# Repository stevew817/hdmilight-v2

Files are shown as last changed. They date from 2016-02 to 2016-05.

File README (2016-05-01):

For latest version, go to http://hacks.esar.org.uk/

How to use:

1) Manufacture the HDMI receiver board that can be found in 
   the 'board' directory (CADSoft Eagle format).
2) Open the 'fpga/hdmilight.xise' project in Xilinx ISE and
   generate a bit file.
3) Edit the files under the config directory to configure
   the LEDs.
4) Edit 'Makefile' in the top level directory and set
   the DATA2MEM path for the Xilinx data2mem tool location
   on your system.
5) Run 'make' in the top level directory, which will build
   'tools/makemem', then the firmware image, then the config
   files, before merging the firmware and config into the
   final bitfile.
   The final result should be hdmilight.bit in the top
   level directory.
6) Upload hdmilight.bit to a Papilio Pro FPGA board
7) Install the HDMI receiver board on to the Papilio board.
8) Connect LED strips to output pins
9) Open a serial terminal to the Papilio
10) Connect HDMI source to receiver board
11) It should now be working.

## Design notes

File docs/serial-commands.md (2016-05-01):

Serial Console Commands
=======================

Get Area
--------

    GA index

* index (0-255): The index or range of indices of the area definition(s) that should be retrieved 

Set Area
--------

    SA index xmin xmax ymin ymax divshift

* index (0-255): The index or range of indices of the area definition(s) that should be set
* xmin (0-63): The left most column of the area's rectangle
* xmax (0-63): The right most column of the area's rectangle
* ymin (0-63): The upper row of the area's rectangle
* ymax (0-63): The lower row of the area's rectangle
* divshift (0-): The number of places to right-shift the accumulated R, G and B value for the area, or in other words the divisor used to calculate the average
 * 1 = divide by 2
 * 2 = divide by 4
 * 3 = divide by 8
 * etc.

Reset Area
----------

    RA

Get Colour Correction Matrix
----------------------------

    GC matrix row 

* matrix (0-15): The index or range of indices of the matrix(s) whose row(s) should be retrieved
* row (0-3): The index or range of indices of the row(s) that should be retrieved:
  * Row 0: defines how red input influences the output R, G and B
  * Row 1: defines how green input influences the output R, G and B
  * Row 2: defines how blue input influences the output R, G and B
  * Row 3: defines the constant value that should be applied to the output R, G and B

Set Colour Correction Matrix
----------------------------

    SC matrix row r g b

* matrix (0-15): The index or range of indices of the matrix(s) whose row(s) should be set
* row (0-3): The index or range of indices of the row(s) that should be set
* r (-255.999-255.999): The coefficient for R
* g (-255.999-255.999): The coefficient for G
* b (-255.999-255.999): The coefficient for B

Reset Colour Correction Matrix
------------------------------

    RC

The reset colour command resets all colour correction matrices to the identity matrix.

Get Delay
---------

    GD

Set Delay
---------

    SD frames usec smooth_ratio

* frames (0-7): The number of whole frames that the output should be delayed by
* usec (0-65535): The number of micro-seconds that the output should be delayed by
* smooth_ratio (0.000-1.000): A number that specifies how much of the new output colour comes from the previous output colour and how much comes from the current frame:
 * 0.000 = 100% from current frame
 * 1.000 = 100% from previous output

Reset Delay
-----------

    RD

The reset delay command disables all delay and temporal smoothing

Disable Format Switching
------------------------

    DF

The disable format switching command stops configurations from being loaded
from flash whenever the format of the incoming video changes.

Enable Format Switching
-----------------------

    EF

The enable format switching command enables loading of the configurations
specified in the format table when the input video format changes.

Get Gamma
---------

    GG table channel index

* table (0-7): The index or range of indices of the gamma correction table(s) whose values should be retrieved
* channel (0-2): The index or range of indices of the colour channel(s) whose values should be retrieved: 
 * 0 = red
 * 1 = green
 * 2 = blue
* index: The index or range of indices of the row(s) that should be retrieved (0-255)

Set Gamma
---------

    SG table channel index value

* table (0-7): The index or range of indices of the gamma correction table(s) whose values should be set
* channel (0-2): The index or range of indices of the colour channel(s) whose values should be set
* index (0-255): The index or range of indices of the row(s) that should be set

Reset Gamma
-----------

    RG

The reset gamma command resets all gamma tables to a linear ramp (gamma 1.0)

Get I2C
-------

    GI addr subaddr

* addr (0-255): The address of the component within the ADV7611 that should be queried:
 * IO: 0x98
 * CP: 0x44
 * HDMI: 0x68
 * Repeater: 0x64
 * EDID: 0x6C
 * InfoFrame: 0x7C
 * CEC: 0x80
 * DPLL: 0x4C
* subaddr (0-255): The address within the component that should be queried

Set I2C
-------

    SI addr subaddr value

* addr (0-255): The address of the component within the ADV7611 that should be queried:
 * IO: 0x98
 * CP: 0x44
 * HDMI: 0x68
 * Repeater: 0x64
 * EDID: 0x6C
 * InfoFrame: 0x7C
 * CEC: 0x80
 * DPLL: 0x4C
* subaddr (0-255): The address within the component that should be queried
* value (0-255): The value that should be written to the register

Reset I2C
---------

    RI

The reset I2C command sets the registers as described in the table
in config_hdmi.h

Get Memory
----------

    GM index

* index (0-63): The index of the configuration that should be retrieved from flash

Get Output Map
--------------

    GO output light

* output (0-7): The index or indices of the output channels whose mapping should be retrieved
* light (0-511): The index or indices of the LED(s) whose mapping should be retrieved

Set Output Map
--------------

    SO output light area colour gamma enable

* output (0-7): The index or indices of the output channels whose mapping should be set
* light (0-511): The index or indices of the LED(s) whose mapping should be set
* area (0-255): The index of the area definition that the LED(s) should use
* colour (0-15): The index of the colour matrix that the LED(s) shoudl use
* gamma (0-7): The index of the gamma table that the LED(s) should use
* enable (0-1): 
 * 1 = enabled
 * 0 = disabled

Reset Output
------------

    RO

The reset output command sets the first 256 LEDs for all outputs to use the 256 area definitions in order, so LED 0 uses area 0, LED 1 uses area 1, and so on. All LEDs are set to use colour matrix 0 and gamma table 0. The remaining 256 LEDs on each output are disabled.

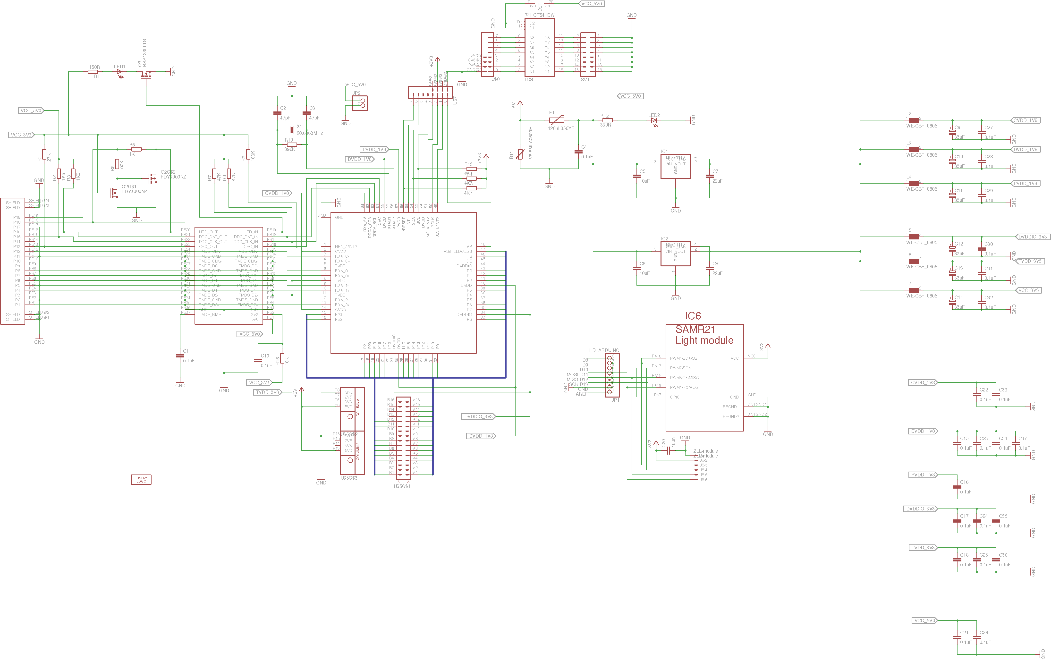
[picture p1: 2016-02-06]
board/hdmilight-schematic-v1.1-Duo.png

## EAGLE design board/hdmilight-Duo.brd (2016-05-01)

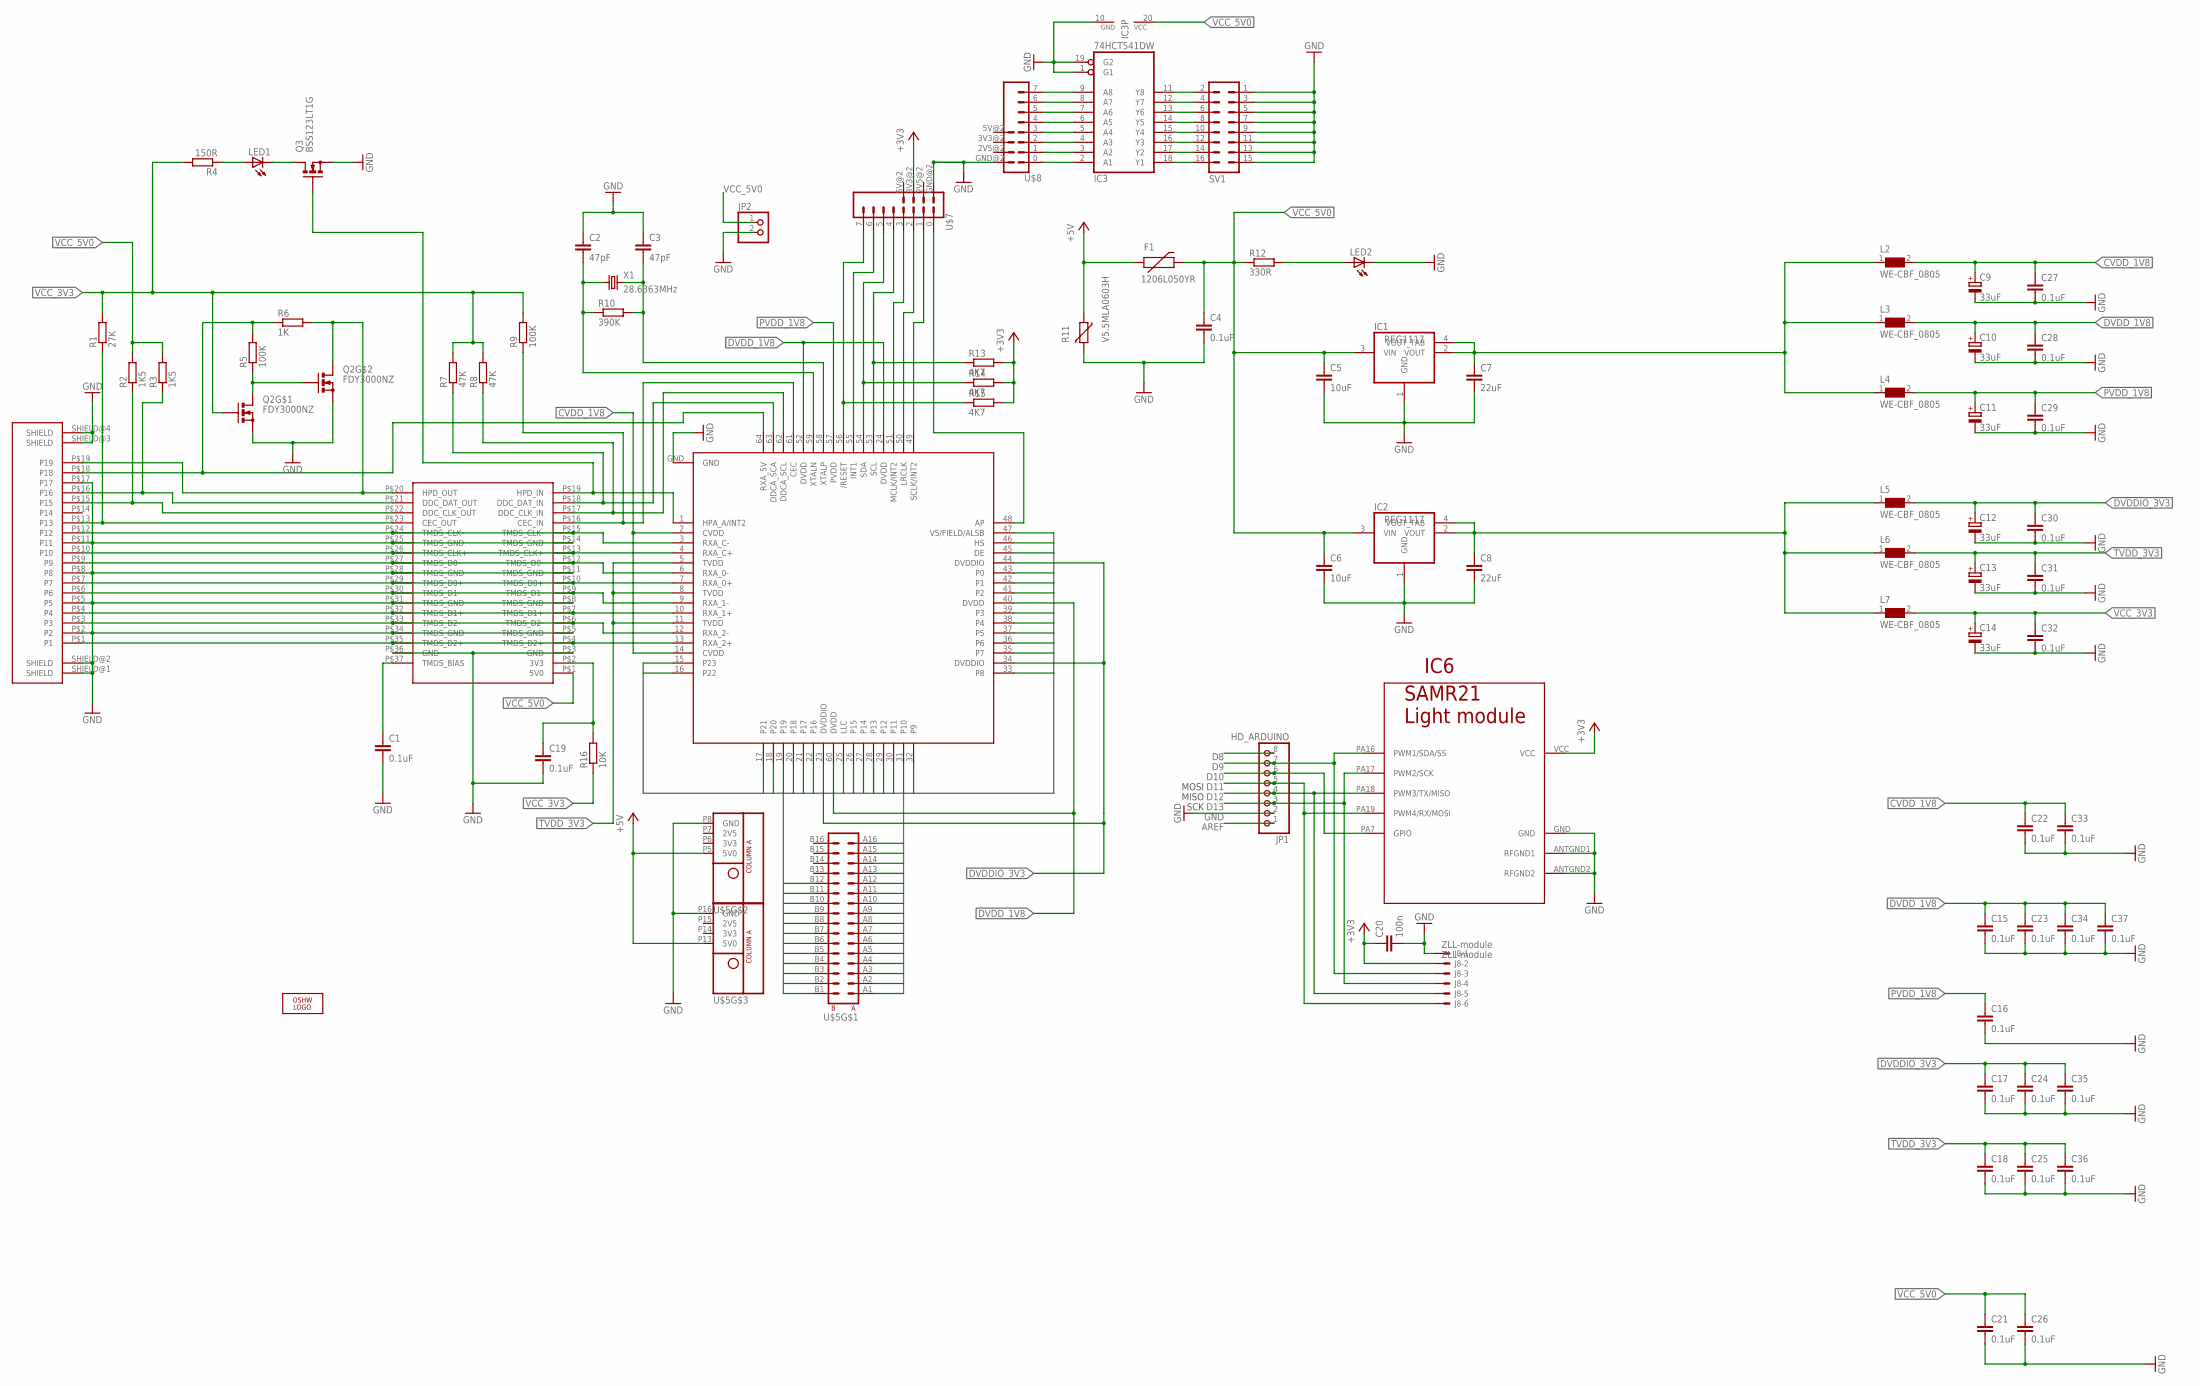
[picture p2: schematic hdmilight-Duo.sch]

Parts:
C1, C4, C16, C17, C19, C21, C22, C24, C26, C27, C28, C29, C30, C31, C32, C33: 0.1uF; C0603
C2, C3: 47pF; C0603
C5, C6: 10uF; C1210
C7, C8: 22uF; C1206
C9, C10, C11, C12, C13, C14: 33uF; SMC_B
C15, C18, C23, C25, C34, C35, C36, C37: 0.1uF; C0402
C20: 100n; C0603K
F1: 1206L050YR; PTC-1206
IC1, IC2: REG1117; SOT223
IC3: 74HCT541DW; SO20W
IC4: ADV7611; TQFP64-10X10
IC5: TPD12S520; TSSOP38
IC6: SAMR21-MODLL; SAMR21-LLMOD
J1: FCI_HDMI_SOCKET_10029449-001RCF
J8: ZLL-module; 331-06
JP1: HD_ARDUINO; 1X08/OCT
JP2: PINHD-1X2/OCT; 1X02/OCT
L2, L3, L4, L5, L6, L7: WE-CBF_0805; 0805
LED1, LED2: LEDCHIP-LED0805; CHIP-LED0805
LOGO1: OSHW_LOGO_FILLX0200-NT; OSHW_FILLX200_NOTEXT
Q2: FDY3000NZ; SC89-6
Q3: BSS123LT1G; SOT23
R1: 27K; R0603
R2, R3: 1K5; R0603
R4: 150R; R0603
R5, R9: 100K; R0603
R6: 1K; R0603
R7, R8: 47K; R0603
R10: 390K; R0603
R11: V5.5MLA0603H; CT/CN0603
R12: 330R; R0603
R13, R14, R15: 4K7; R0603
R16: 10K; R0603
SV1: MA08-2
U$5: WING32_HALF; WING32_HALF_NOHOLES
U$7, U$8: WING8WING8_NOHOLES; WINGSIDE_8BIT_NOHOLES
X1: 28.6363MHz; SM49

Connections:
+3V3: C20.1, IC6.VCC, J8.3, R13.2, R14.2, R15.2, U$7.3V3@2 (3V3)
+5V: F1.1, R11.1, U$5.P5 (5V0), U$5.P13 (5V0)
AP: IC4.48 (AP), U$7.0 (1)
AREF: JP1.1
CVDD_1V8: C9.+, C22.1, C27.1, C33.1, IC4.2 (CVDD), IC4.14 (CVDD), L2.2
D8: JP1.8
D9: IC6.PA16 (PWM1/SDA/SS), J8.5, JP1.7
D10: IC6.PA7 (GPIO), JP1.6
D11: IC6.PA19 (PWM4/RX/MOSI), J8.11, JP1.5
D12: IC6.PA18 (PWM3/TX/MISO), J8.9, JP1.4
D13: IC6.PA17 (PWM2/SCK), J8.7, JP1.3
DE: IC4.45 (DE), U$5.B2
DVDDIO_3V3: C12.+, C17.1, C24.1, C30.1, C35.1, IC4.23 (DVDDIO), IC4.34 (DVDDIO), IC4.44 (DVDDIO), L5.2
DVDD_1V8: C10.+, C15.1, C23.1, C28.1, C34.1, C37.1, IC4.24 (DVDD), IC4.40 (DVDD), IC4.52 (DVDD), IC4.60 (DVDD), L3.2
GND: C1.2, C2.1, C3.1, C4.2, C5.2, C6.2, C7.2, C8.2, C9.-, C10.-, C11.-, C12.-, C13.-, C14.-, C15.2, C16.2, C17.2, C18.2, C19.2, C20.2, C21.2, C22.2, C23.2, C24.2, C25.2, C26.2, C27.2, C28.2, C29.2, C30.2, C31.2, C32.2, C33.2, C34.2, C35.2, C36.2, C37.2, IC1.1 (GND), IC2.1 (GND), IC3.1 (G1), IC3.10 (GND), IC3.19 (G2), IC4.GND, IC5.P$3 (GND), IC5.P$5 (TMDS_GND), IC5.P$8 (TMDS_GND), IC5.P$11 (TMDS_GND), IC5.P$14 (TMDS_GND), IC5.P$25 (TMDS_GND), IC5.P$28 (TMDS_GND), IC5.P$31 (TMDS_GND), IC5.P$34 (TMDS_GND), IC5.P$36 (GND), IC6.ANTGND1 (RFGND1), IC6.ANTGND2 (RFGND2), IC6.GND, J1.P$2 (P2), J1.P$5 (P5), J1.P$8 (P8), J1.P$11 (P11), J1.P$17 (P17), J1.SHIELD@1 (SHIELD), J1.SHIELD@2 (SHIELD), J1.SHIELD@3 (SHIELD), J1.SHIELD@4 (SHIELD), J8.1, JP1.2, JP2.2, LED2.C, Q2.P$1 (S), Q2.P$4 (S), Q3.2 (S), R11.2, SV1.1, SV1.3, SV1.5, SV1.7, SV1.9, SV1.11, SV1.13, SV1.15, U$5.P8 (GND), U$5.P16 (GND), U$7.GND@2 (GND), U$8.GND@2 (GND)
HS: IC4.46 (HS), U$5.A1
INT1: IC4.55 (INT1), U$7.6 (7)
LLC: IC4.25 (LLC), U$5.A14
LRCLK: IC4.50 (LRCLK), U$7.2 (3)
MCLK: IC4.51 (MCLK/INT2), U$7.3 (4)
unnamed: IC4.13 (RXA_2+), IC5.P$4 (TMDS_D2+), IC5.P$35 (TMDS_D2+), J1.P$1 (P1)
unnamed: IC4.12 (RXA_2-), IC5.P$6 (TMDS_D2-), IC5.P$33 (TMDS_D2-), J1.P$3 (P3)
unnamed: IC4.10 (RXA_1+), IC5.P$7 (TMDS_D1+), IC5.P$32 (TMDS_D1+), J1.P$4 (P4)
unnamed: IC4.9 (RXA_1-), IC5.P$9 (TMDS_D1-), IC5.P$30 (TMDS_D1-), J1.P$6 (P6)
unnamed: IC4.7 (RXA_0+), IC5.P$10 (TMDS_D0+), IC5.P$29 (TMDS_D0+), J1.P$7 (P7)
unnamed: IC4.6 (RXA_0-), IC5.P$12 (TMDS_D0-), IC5.P$27 (TMDS_D0-), J1.P$9 (P9)
unnamed: IC4.4 (RXA_C+), IC5.P$13 (TMDS_CLK+), IC5.P$26 (TMDS_CLK+), J1.P$10 (P10)
unnamed: IC4.3 (RXA_C-), IC5.P$15 (TMDS_CLK-), IC5.P$24 (TMDS_CLK-), J1.P$12 (P12)
unnamed: IC3.9 (A8), U$8.7 (8)
unnamed: IC3.8 (A7), U$8.6 (7)
unnamed: IC3.7 (A6), U$8.5 (6)
unnamed: IC3.6 (A5), U$8.4 (5)
unnamed: IC5.P$23 (CEC_OUT), J1.P$13 (P13), R1.1
unnamed: IC5.P$22 (DDC_CLK_OUT), J1.P$15 (P15), R2.1
unnamed: IC5.P$21 (DDC_DAT_OUT), J1.P$16 (P16), R3.1
unnamed: IC5.P$20 (HPD_OUT), J1.P$19 (P19), Q2.P$3 (D), R6.2
unnamed: IC3.5 (A4), U$8.3 (4)
unnamed: IC3.4 (A3), U$8.2 (3)
unnamed: LED2.A, R12.2
unnamed: IC4.62 (DDCA_SCL), IC5.P$17 (DDC_CLK_IN), R8.1
unnamed: C8.1, IC2.2 (VOUT), IC2.4 (VOUT_TAB), L5.1, L6.1, L7.1
unnamed: C7.1, IC1.2 (VOUT), IC1.4 (VOUT_TAB), L2.1, L3.1, L4.1
unnamed: IC4.63 (DDCA_SCA), IC5.P$18 (DDC_DAT_IN), R7.1
unnamed: IC4.61 (CEC), IC5.P$16 (CEC_IN), R9.1
unnamed: C2.2, IC4.59 (XTALN), R10.1, X1.1
unnamed: C3.2, IC4.58 (XTALP), R10.2, X1.2
unnamed: C1.1, IC5.P$37 (TMDS_BIAS)
unnamed: IC3.3 (A2), U$8.1 (2)
unnamed: IC3.2 (A1), U$8.0 (1)
unnamed: IC3.11 (Y8), SV1.2
unnamed: IC3.12 (Y7), SV1.4
unnamed: IC3.13 (Y6), SV1.6
unnamed: IC3.15 (Y4), SV1.10
unnamed: IC3.16 (Y3), SV1.12
unnamed: IC3.17 (Y2), SV1.14
unnamed: IC3.18 (Y1), SV1.16
unnamed: IC3.14 (Y5), SV1.8
unnamed: C19.1, IC5.P$2 (3V3), R16.2
unnamed: Q2.P$5 (G), Q2.P$6 (D), R5.1
unnamed: IC4.64 (RXA_5V), J1.P$18 (P18), R5.2, R6.1
unnamed: LED1.A, R4.1
unnamed: LED1.C, Q3.3 (D)
unnamed: IC4.1 (HPA_A/INT2), IC5.P$19 (HPD_IN), Q3.1 (G)
NRESET: IC4.56 (/RESET), R15.1, U$7.7 (8)
P0: IC4.43 (P0), U$5.A2
P1: IC4.42 (P1), U$5.B3
P2: IC4.41 (P2), U$5.A3
P3: IC4.39 (P3), U$5.B4
P4: IC4.38 (P4), U$5.A4
P5: IC4.37 (P5), U$5.B5
P6: IC4.36 (P6), U$5.A5
P7: IC4.35 (P7), U$5.B6
P8: IC4.33 (P8), U$5.A6
P9: IC4.32 (P9), U$5.B7
P10: IC4.31 (P10), U$5.A7
P11: IC4.30 (P11), U$5.B8
P12: IC4.29 (P12), U$5.A8
P13: IC4.28 (P13), U$5.B9
P14: IC4.27 (P14), U$5.A9
P15: IC4.26 (P15), U$5.B10
P16: IC4.22 (P16), U$5.A10
P17: IC4.21 (P17), U$5.B11
P18: IC4.20 (P18), U$5.A11
P19: IC4.19, U$5.B12
P20: IC4.18 (P20), U$5.A12
P21: IC4.17 (P21), U$5.A13
P22: IC4.16 (P22), U$5.A15
P23: IC4.15 (P23), U$5.A16
PVDD_1V8: C11.+, C16.1, C29.1, IC4.57 (PVDD), L4.2
SCL: IC4.53 (SCL), R13.1, U$7.4 (5)
SCLK: IC4.49 (SCLK/INT2), U$7.1 (2)
SDA: IC4.54 (SDA), R14.1, U$7.5 (6)
TVDD_3V3: C13.+, C18.1, C25.1, C31.1, C36.1, IC4.5 (TVDD), IC4.8 (TVDD), IC4.11 (TVDD), L6.2
VCC_3V3: C14.+, C32.1, L7.2, Q2.P$2 (G), R1.2, R4.2, R7.2, R8.2, R9.2, R16.1
VCC_5V0: C4.1, C5.1, C6.1, C21.1, C26.1, F1.2, IC1.3 (VIN), IC2.3 (VIN), IC3.20 (VCC), IC5.P$1 (5V0), JP2.1, R2.2, R3.2, R12.1
VS: IC4.47 (VS/FIELD/ALSB), U$5.B1

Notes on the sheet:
MOSI
MISO
SCK

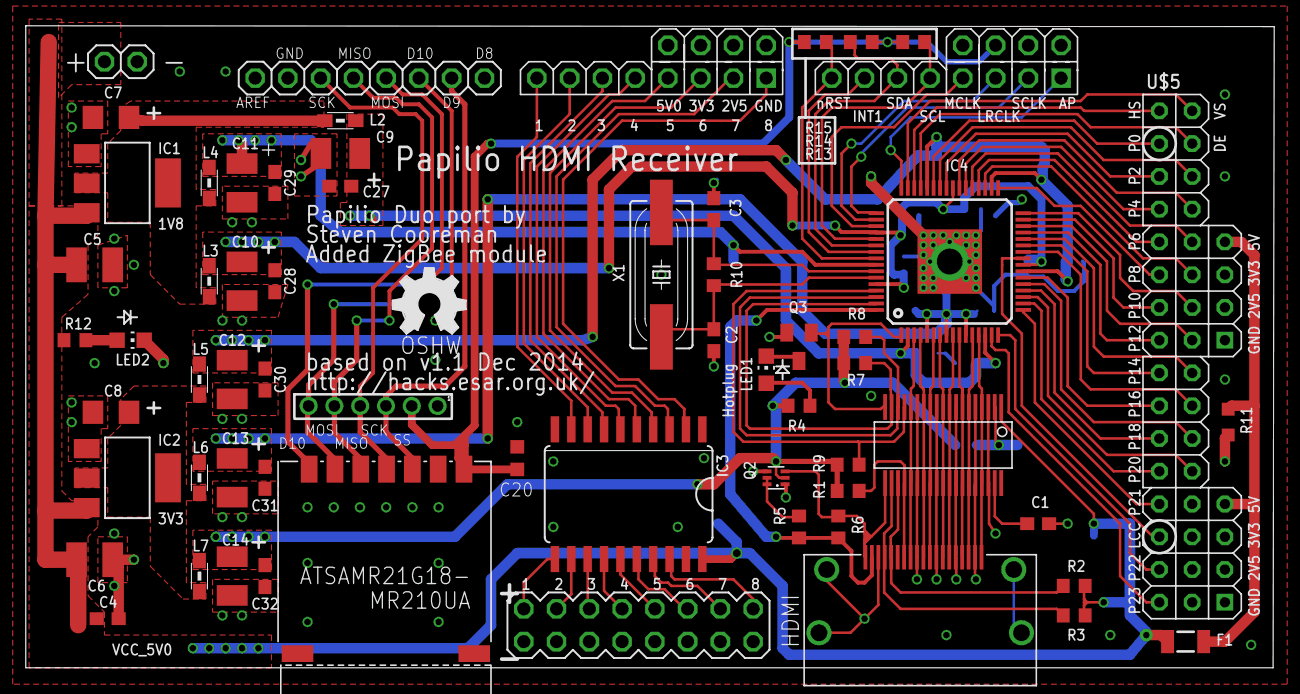
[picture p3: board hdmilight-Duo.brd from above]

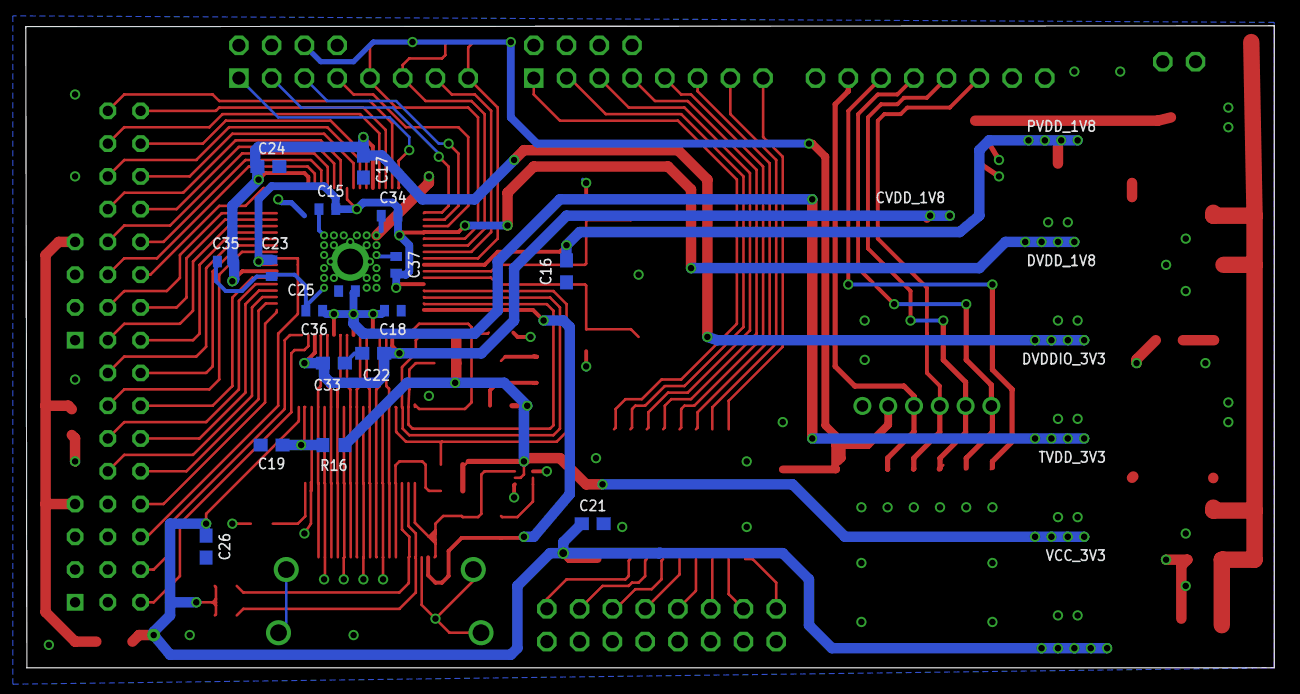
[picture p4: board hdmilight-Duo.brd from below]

Board: 2 copper layers, 96.8 x 49.8 mm, 80 parts (17 on the bottom side), 94 nets.

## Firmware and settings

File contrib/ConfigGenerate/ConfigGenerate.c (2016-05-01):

/*

   Copyright (C) 2015 Jetty

   This file is part of HDMI-Light

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
*/

#include <stdio.h>
#include <math.h>

/*
	Generates a basic Hdmilight configuration that has strips of LEDs wired in the following order on 1 output.  The intention
	is to provide a simple configuration to begin with, that can be adapted later:

	Wire in this order:
		Power/Data -> Top (Going Left to Right)
		Right (Going Top to Bottom)
		Bottom (Going Right to Left)
		Left (Going Bottom to Top)

	The following files are generated:
		area.conf
		output_N.conf

	It's assumed that top/bottom led strips  have the same number of leds and left/right leds strips have the same number of leds

	The total number of LEDS must be <=512
*/

// The number of the output we want to generate the files for
#define	OUTPUT_NUM 0 	// Valid values are 0-7 (and integer) and map to outputs 1-8 on the Hdmilight v2 board

// Set to the width / height of the picture (you can obtain this via the GF (get format) command in the serial interface
#define PIXELS_WIDTH  1916	// Must be integer
#define PIXELS_HEIGHT 1080	// Must be integer

// LEDS_X * 2 + LEDS_Y * 2  must be <= 512, if it's not, then your configuration will span more than 1 output, and this
// tool is not for you
#define LEDS_X	64	// Number of X leds (number of LEDs in each of the Top and Bottom Rows), must be integer
#define LEDS_Y	36	// Number of Y leds (number of LEDs in each of the Left and Right Columns, must be integer

// Fine tuning the bounds of the screen
// The screen is divided into a grid of cells of VIDEO_SCALING x VIDEO_SCALING in pixels by the FPGA
// Because the picture may not fit completely in the cell grid, we provide the opportunity here to adjust the 
// the bounds of the cell grid.  Negative values will shift the cell grid boudns to the left, and positive values to the right.
// The starting offsets should be >= 0, and values -2 to 2 would be normal.
// Start off with the values at 0, if you have a left most led in X that is not displaying a color, the video is out of bounds,
// increase by 1 and try again.  If the right most led in X is not correct, then you will want to decrease the end X offset by 1
//
// The cell grid could like this before adjustment, where P is the picture.  Both P and X are units of VIDEO_SCALING * VIDEO_SCALING
// in size:
//  X X X X X X X X X X X X X
//  X P P P P P P P P P P P X
//  X P P P P P P P P P P P X
//  X P P P P P P P P P P P X
//  X P P P P P P P P P P P X
//  X P P P P P P P P P P P X
//
//  To fix this and achieve:
//  P P P P P P P P P P P
//  P P P P P P P P P P P
//  P P P P P P P P P P P
//  P P P P P P P P P P P
//  P P P P P P P P P P P
//
//	CELLGRID_BOUNDS_START_X_OFFSET 	1
//	CELLGRID_BOUNDS_END_X_OFFSET	-1
//	CELLGRID_BOUNDS_START_Y_OFFSET 	1
//	CELLGRID_BOUNDS_END_Y_OFFSET	0
//
#define CELLGRID_BOUNDS_START_X_OFFSET 	0	// Adjustment to the first cell we want to use for the LEDS, must be >=0, typically <=2 and integer
#define CELLGRID_BOUNDS_END_X_OFFSET	0	// Adjustment to the last cell we want to use for the LEDS, typically -2 to +2 and integer
#define CELLGRID_BOUNDS_START_Y_OFFSET 	0	// Adjustment to the first cell we want to use for the LEDS, must be >=0, typically <=2 and integer
#define CELLGRID_BOUNDS_END_Y_OFFSET	0	// Adjustment to the last cell we want to use for the LEDS, typically -2 to +2 and integer

// The cell grid is further divided into areas which surround the outside the screen
// The following are in units of cells and are integers.  The minimum size is 1 cell.
// 
// For the top/bottom rows, AREA_WIDTH is in X and AREA_DEPTH is in Y, i.e AREA_WIDTH=2, AREA_DEPTH = 8, defines an area that is sized
// X: 2 * VIDEO_SCALING and Y:8 * VIDEO_SCALING
//
// For the left/right columns, AREA_WIDTH is in Y and AREA_DEPTH is in X, i.e AREA_WIDTH=2, AREA_DEPTH = 8, defines an area that is sized
// Y: 2 * VIDEO_SCALING and X:8 * VIDEO_SCALING
//
// Normally, where you have more LEDs than cells, you would have an AREA_WIDTH = 1
// If you have significantly fewer LEDS than cells, then AREA_WIWDTH = 2, or maybe 3
//
// AREA_DEPTH controls have far the sample area stretches from the edges of the screen.  Larger numbers take a large
// sample area to calculate the resulting color of the LED
//
// AREA_WIDTH * AREA_HEIGHT must be a power of 2 i.e. valid values are 1, 2, 4, 8, 16, 32 etc.
//
// The number of areas must be <= 255, therefore:
//	 ( ((ceilf(PIXELS_WIDTH / VIDEO_SCALING) / AREA_WIDTH) * 2 + 
//	   ((ceilf(PIXELS_HEIGHT / VIDEO_SCALING) / AREA_WIDTH) * 2 ) must be less than 255
#define AREA_WIDTH 1	// >=1 and integer:  Typically 1 or 2 (if you have fewer LEDs per strip)
#define AREA_DEPTH 8	// >=1 and integer:  Start at 8, and reduce after you've tuned CELLGRID_BOUNDS

// Defining the letter box ratio avoids having to change the CELLGRID_BOUNDS and LEDS_BOUNDS
// for different Letterbox formats at the same resolution.
// To use this, define CELLGRID_BOUNDS / LEDS_BOUNDS for the base resolution defined in PIXELS_WIDTH/HEIGHT,
// and then generate configs with a different LETTERBOX_RATIO for the letterboxes required
// Note that the base letterbox ratio is calculated from PIXELS_WIDTH/HEIGHT, so if that ratio is 1.77,
// and LETTERBOX_RATIO is 1.77, then there is no change made to the bounds of the screen
// Letterbox ratio must be > 0.0
#define LETTERBOX_RATIO 1.77	// 16:9
//#define LETTERBOX_RATIO 2.40	// Modern anamorphic (2-4-0)
//#define LETTERBOX_RATIO 1.33	// 4:3

// If the span of leds exceed the displayed picture area, there will be leds that should be dark,
// but because they are not are causing leds to not line up with the picture.
// Force the leds to be ignored by adjusting the bounds of the LED causing outermost leds to be ignored 
#define LEDS_BOUNDS_START_X_OFFSET 	0	// Adjustment to the first led we want to use, must be >=0, typically <=2 and integer
#define LEDS_BOUNDS_END_X_OFFSET	0	// Adjustment to the last led we want to use, must be <= 0, typically >=-2 and integer
#define LEDS_BOUNDS_START_Y_OFFSET 	0	// Adjustment to the first led we want to use, must be >=0, typically <=2 and integer
#define LEDS_BOUNDS_END_Y_OFFSET	0	// Adjustment to the last led we want to use, must be <=0, typically <=-2 and integer

// The color value for the output table for leds in use
#define COLOR_ACTIVE 0

// The color value for the output table for leds that are disabled
// Set this color in the color_N.conf to black (0's for everything)
#define COLOR_DISABLED 1

// The gamma value for the output table
#define GAMMA 1




// DO NOT CHANGE BELOW HERE
#define VIDEO_SCALING 32	// Incoming video is scaled down by this amount in X/Y by the FPGA.  I.e. 1920x1080 / 32 = 60x33
				// Scaling is independent of resolution, so 640x480 is 20x15

#define AREA_CONF		"area.conf"
#define OUTPUT_CONF_PART1	"output_"
#define OUTPUT_CONF_PART2	".conf"

#define LEDS_WIDTH  ((LEDS_X) + (LEDS_BOUNDS_END_X_OFFSET) - (LEDS_BOUNDS_START_X_OFFSET))
#define LEDS_HEIGHT ((LEDS_Y) + (LEDS_BOUNDS_END_Y_OFFSET) - (LEDS_BOUNDS_START_Y_OFFSET))

#define LETTERBOX_FUDGE_FACTOR (0.01)

#define SCREEN_ASPECT_RATIO ((float)(PIXELS_WIDTH) / (float)(PIXELS_HEIGHT))



// Returns true if v is integer
// otherwise false

int isInteger(float v)
{
	if (((float)((int)v)) == v )	return 1;
	else				return 0;
}



// Verifies the settings are valid
// Returns true if okay, otherwise false

int verifySettings(void)
{
	if ( OUTPUT_NUM < 0 || OUTPUT_NUM > 7 || ( ! isInteger(OUTPUT_NUM) ) )	{fprintf(stderr, "Error: OUTPUT_NUM should be 0..7 and integer\n");return 0;}
	if ( PIXELS_WIDTH < 1 || (! isInteger(PIXELS_WIDTH) ) )			{fprintf(stderr, "Error: PIXELS_WIDTH should be >=1 and integer\n");return 0;}
	if ( PIXELS_HEIGHT < 1 || (! isInteger(PIXELS_HEIGHT) ) )		{fprintf(stderr, "Error: PIXELS_HEIGHT should be >=1 and integer\n");return 0;}
	if ( LEDS_X < 1 || (! isInteger(LEDS_X) ) )				{fprintf(stderr, "Error: LEDS_X should be >=1 and integer\n");return 0;}
	if ( LEDS_Y < 1 || (! isInteger(LEDS_Y) ) )				{fprintf(stderr, "Error: LEDS_Y should be >=1 and integer\n");return 0;}

	if (( LEDS_X * 2 + LEDS_Y * 2 ) > 512)
		{fprintf(stderr, "Error: Total number of LEDs is greater than 512 and will exceed 1 output, this utility is not for you!\n");return 0;}

	if ( CELLGRID_BOUNDS_START_X_OFFSET < 0 || (! isInteger(CELLGRID_BOUNDS_START_X_OFFSET) ) )
										{fprintf(stderr, "Error: CELLGRID_BOUNDS_START_X_OFFSET should be >=0 and integer\n");return 0;}
	if ( ! isInteger(CELLGRID_BOUNDS_END_X_OFFSET) )			{fprintf(stderr, "Error: CELLGRID_BOUNDS_END_X_OFFSET should be integer\n");return 0;}
	if ( CELLGRID_BOUNDS_START_Y_OFFSET < 0 || (! isInteger(CELLGRID_BOUNDS_START_Y_OFFSET) ) )
										{fprintf(stderr, "Error: CELLGRID_BOUNDS_START_Y_OFFSET should be >=0 and integer\n");return 0;}
	if ( ! isInteger(CELLGRID_BOUNDS_END_Y_OFFSET) )			{fprintf(stderr, "Error: CELLGRID_BOUNDS_END_Y_OFFSET should be integer\n");return 0;}
	if ( AREA_WIDTH < 1 || (! isInteger(AREA_WIDTH) ) )			{fprintf(stderr, "Error: AREA_WIDTH should be >=1 and integer\n");return 0;}
	if ( AREA_DEPTH < 1 || (! isInteger(AREA_DEPTH) ) )			{fprintf(stderr, "Error: AREA_DEPTH should be >=1 and integer\n");return 0;}
	
	// Test for a power of 2 by shifting to the right
	int size = AREA_WIDTH * AREA_DEPTH;
	while ( size > 0 )
	{
		// Tes for more than one bit set
		if ( size > 1 && (size & 1))	break;
		size >>= 1;	// Shift right
	}

	// If size is not zero, then we broke out of the while above due to more than one bit being set
	// If size is 0, then we only had one bit set (i.e. a power of 2)
	if ( size )	{fprintf(stderr, "Error: AREA_WIDTH * AREA_DEPTH should be a power of 2\n");return 0;}

	if  ( ((ceilf((float)PIXELS_WIDTH  / (float)VIDEO_SCALING) / (float)AREA_WIDTH) * 2.0 +
	      ((ceilf((float)PIXELS_HEIGHT / (float)VIDEO_SCALING) / (float)AREA_WIDTH) * 2.0) ) > 255.0 )
			{fprintf(stderr, "Error: 255 Areas exceeded, increase AREA_WIDTH by 1\n");return 0;}

	if ( LEDS_BOUNDS_START_X_OFFSET < 0 || ( ! isInteger(LEDS_BOUNDS_START_X_OFFSET) ) )
		{fprintf(stderr, "Error: LEDS_BOUNDS_START_X_OFFSET should be >=0 and integer\n");return 0;}
	if ( LEDS_BOUNDS_START_Y_OFFSET < 0 || ( ! isInteger(LEDS_BOUNDS_START_Y_OFFSET) ) )
		{fprintf(stderr, "Error: LEDS_BOUNDS_START_Y_OFFSET should be >=0 and integer\n");return 0;}
	if ( LEDS_BOUNDS_END_X_OFFSET > 0 || ( ! isInteger(LEDS_BOUNDS_END_X_OFFSET) ) )
		{fprintf(stderr, "Error: LEDS_BOUNDS_END_X_OFFSET should be <=0 and integer\n");return 0;}
	if ( LEDS_BOUNDS_END_Y_OFFSET > 0 || ( ! isInteger(LEDS_BOUNDS_END_Y_OFFSET) ) )
		{fprintf(stderr, "Error: LEDS_BOUNDS_END_Y_OFFSET should be <=0 and integer\n");return 0;}

	if ( LETTERBOX_RATIO <= 0.0 )
		{fprintf(stderr, "Error: LETTER_BOX_RATIO should be >0.0\n");return 0;}
	
	return 1;
}



void areaConfHeader(FILE *fp)
{
	fprintf(fp, "# xmin  xmax  ymin  ymax  divshift area_number\n");
}



FILE *areaConfCreate(void)
{
	FILE *fp, *fopen();

	if (( fp = fopen(AREA_CONF, "w")) == NULL )
		perror(AREA_CONF);

	return fp;
}



void outputConfHeader(FILE *fp)
{
	fprintf(fp, "# index    area    colour    gamma    enable\n");
}



FILE *outputConfCreate(void)
{
	char filename[20];
	FILE *fp, *fopen();

	sprintf(filename, "%s%d%s", OUTPUT_CONF_PART1, OUTPUT_NUM, OUTPUT_CONF_PART2);
	if (( fp = fopen(filename, "w")) == NULL )
		perror(filename);

	return fp;
}



int areaConfGenerate(FILE *fp, int *areasX, int *areasY, float letterBoxXPercent, float letterBoxYPercent)
{
	int i, divshift = 0;

	*areasX = *areasY = 0;

	// Figure out divshift, which is a power of 2, we do this by shifting until areaArea is 0
	int areaArea = AREA_WIDTH * AREA_DEPTH;

	while ( ( areaArea >>= 1 ) )
		divshift ++;
	
	printf("divshift calculated: %d\n", divshift);

	// Calculate the min and max cell values
	int cellMaxX = (int)ceilf((float)PIXELS_WIDTH  / (float)VIDEO_SCALING);
	int cellMaxY = (int)ceilf((float)PIXELS_HEIGHT / (float)VIDEO_SCALING);
	int cellMinX = 0;
	int cellMinY = 0;

	// Adjust the min/max cell values by the bounds offset
	cellMinX += CELLGRID_BOUNDS_START_X_OFFSET;
	cellMaxX += CELLGRID_BOUNDS_END_X_OFFSET;
	cellMinY += CELLGRID_BOUNDS_START_Y_OFFSET;
	cellMaxY += CELLGRID_BOUNDS_END_Y_OFFSET;

	// Figure out the letterbox adjustment
	int letterBoxXAdjust, letterBoxYAdjust;

	if ( letterBoxXPercent == 1.0 )
		letterBoxXAdjust = 0;
	else	letterBoxXAdjust = (int)((1.0 - letterBoxXPercent) * (float)((cellMaxX - cellMinX) + 1) * 0.5);

	if ( letterBoxYPercent == 1.0 )
		letterBoxYAdjust = 0;
	else	letterBoxYAdjust = (int)((1.0 - letterBoxYPercent) * (float)((cellMaxY - cellMinY) + 1) * 0.5);


	int countAreas = 0;

	// Top row running left to right
	fprintf(fp, "# Top Row running left to right\n");
	areaConfHeader(fp);
	for ( i = cellMinX; i <= cellMaxX; i += AREA_WIDTH )
		{ fprintf(fp, "  %-5d %-5d %-5d %-5d %-8d # %d\n", i, (i + AREA_WIDTH) - 1, letterBoxYAdjust + cellMinY, letterBoxYAdjust + (cellMinY + AREA_DEPTH) - 1, divshift, countAreas++); (*areasX) ++; }
	
	// Right column running top to bottom
	fprintf(fp, "# Right Column running top to bottom\n");
	areaConfHeader(fp);
	for ( i = cellMinY; i <= cellMaxY; i += AREA_WIDTH )
		{ fprintf(fp, "  %-5d %-5d %-5d %-5d %-8d # %d\n", -letterBoxXAdjust + (cellMaxX - AREA_DEPTH) + 1, -letterBoxXAdjust + cellMaxX, i, (i + AREA_WIDTH) - 1, divshift, countAreas++); (*areasY) ++; }

	// Bottom row running left to right
	fprintf(fp, "# Bottom Row running left to right\n");
	areaConfHeader(fp);
	for ( i = cellMinX; i <= cellMaxX; i += AREA_WIDTH )
		{ fprintf(fp, "  %-5d %-5d %-5d %-5d %-8d # %d\n", i, (i + AREA_WIDTH) - 1, -letterBoxYAdjust + (cellMaxY - AREA_DEPTH) + 1, -letterBoxYAdjust + cellMaxY, divshift, countAreas++); }

	// Left column running top to bottom
	fprintf(fp, "# Left Column running top to bottom\n");
	areaConfHeader(fp);
	for ( i = cellMinY; i <= cellMaxY; i += AREA_WIDTH )
		{ fprintf(fp, "  %-5d %-5d %-5d %-5d %-8d # %d\n", letterBoxXAdjust + cellMinX, letterBoxXAdjust + (cellMinX + AREA_DEPTH ) - 1, i, (i + AREA_WIDTH) - 1, divshift, countAreas++); }

	printf("Number of areas: %d XAreas: %d YAreas: %d\n", countAreas, *areasX, *areasY);

	return countAreas;
}



int getAreaForLedX(int ind, int areasX)
{
	return (int)(((float)ind / (float)LEDS_WIDTH) * (float)areasX);
}



int getAreaForLedY(int ind, int areasY)
{
	return (int)(((float)ind / (float)LEDS_HEIGHT) * (float)areasY);
}



int dumpDisabledLed(FILE *fp, int count, int ledCount)
{
	int i;

	for ( i = 0; i < count; i ++, ledCount ++ )
		fprintf(fp, "%7d %7d %9d %8d %9d\n", ledCount, 0, COLOR_DISABLED, GAMMA, 1);

	return ledCount++;
}



int dumpActiveLed(FILE *fp, int from, int to, int ledCount, int baseArea, int x, int areas)
{
	int i;

	if 	( to > from )
	{
		for ( i = from; i < to; i ++, ledCount ++ )
			fprintf(fp, "%7d %7d %9d %8d %9d\n", ledCount, baseArea + ((x) ? getAreaForLedX(i, areas) : getAreaForLedY(i, areas)), COLOR_ACTIVE, GAMMA, 1);
	}
	else if ( to < from )
	{
		for ( i = from - 1; i >= to; i --, ledCount ++ )
			fprintf(fp, "%7d %7d %9d %8d %9d\n", ledCount, baseArea + ((x) ? getAreaForLedX(i, areas) : getAreaForLedY(i, areas)), COLOR_ACTIVE, GAMMA, 1);
	}


	return ledCount;
}



int aspectRatioMatch(float aspectRatio1, float aspectRatio2)
{
	if ( fabsf(aspectRatio2 - aspectRatio1) <= LETTERBOX_FUDGE_FACTOR ) return 1;
	return 0;
}



// Figure out the percentage (0-1) we need to adjust X or Y for letter boxing

void calculateLetterBoxAdjustment(float *letterBoxXPercent, float *letterBoxYPercent)
{
	if ( aspectRatioMatch( SCREEN_ASPECT_RATIO, LETTERBOX_RATIO ) )
	{
		*letterBoxXPercent = *letterBoxYPercent = 1.0;
	}
	else if ( (LETTERBOX_RATIO) > SCREEN_ASPECT_RATIO )
	{
		*letterBoxXPercent = 1.0;
		*letterBoxYPercent = SCREEN_ASPECT_RATIO / (LETTERBOX_RATIO); 
	}
	else if ( (LETTERBOX_RATIO) < SCREEN_ASPECT_RATIO )
	{
		*letterBoxXPercent = (LETTERBOX_RATIO) / SCREEN_ASPECT_RATIO; 
		*letterBoxYPercent = 1.0;
	}	
}



void outputConfGenerate(FILE *fp, int areasX, int areasY)
{
	int i, ledCount = 0, baseArea = 0;

	// Top Row running left to right
	fprintf(fp, "# Top Row running left to right\n");
	outputConfHeader(fp);
	ledCount = dumpDisabledLed(fp, LEDS_BOUNDS_START_X_OFFSET, ledCount);
	ledCount = dumpActiveLed(fp, 0, LEDS_WIDTH, ledCount, baseArea, 1, areasX);
	ledCount = dumpDisabledLed(fp, -LEDS_BOUNDS_END_X_OFFSET, ledCount);

	// Right Column running top to bottom
	fprintf(fp, "# Right Column running top to bottom\n");
	outputConfHeader(fp);
	baseArea += areasX;
	ledCount = dumpDisabledLed(fp, LEDS_BOUNDS_START_Y_OFFSET, ledCount);
	ledCount = dumpActiveLed(fp, 0, LEDS_HEIGHT, ledCount, baseArea, 0, areasY);
	ledCount = dumpDisabledLed(fp, -LEDS_BOUNDS_END_Y_OFFSET, ledCount);

	// Bottom Row running right to left
	fprintf(fp, "# Bottom Row running right to left\n");
	outputConfHeader(fp);
	baseArea += areasY;
	ledCount = dumpDisabledLed(fp, -LEDS_BOUNDS_END_X_OFFSET, ledCount);
	ledCount = dumpActiveLed(fp, LEDS_WIDTH, 0, ledCount, baseArea, 1, areasX);
	ledCount = dumpDisabledLed(fp, LEDS_BOUNDS_START_X_OFFSET, ledCount);

	// Left Column running bottom to top
	fprintf(fp, "# Left Column running bottom to top\n");
	outputConfHeader(fp);
	baseArea += areasX;
	ledCount = dumpDisabledLed(fp, -LEDS_BOUNDS_END_Y_OFFSET, ledCount);
	ledCount = dumpActiveLed(fp, LEDS_HEIGHT, 0, ledCount, baseArea, 0, areasY);
	ledCount = dumpDisabledLed(fp, LEDS_BOUNDS_START_Y_OFFSET, ledCount);

	printf("%d leds written to output, filled to 512\n", ledCount);

	// Disable the remainder of the leds in the channel
	fprintf(fp, "# Remaining LEDs are disabled\n");
	outputConfHeader(fp);
	ledCount = dumpDisabledLed(fp, 512-ledCount, ledCount);
}



int main(void)
{
	int areasX, areasY;
	FILE *areaConfFp, *outputConfFp;
	float letterBoxYPercent, letterBoxXPercent;

	if ( ! verifySettings() )	return 1;

	// Open the files and create the headers
	if (( areaConfFp   = areaConfCreate()   ) == NULL )	return 2;
	if (( outputConfFp = outputConfCreate() ) == NULL )	return 3;

	// Calculate the adjustment for letter boxing
	calculateLetterBoxAdjustment(&letterBoxXPercent, &letterBoxYPercent);

	// Generate area file contents
	areaConfGenerate(areaConfFp, &areasX, &areasY, letterBoxXPercent, letterBoxYPercent);

	// Generate output file contents
	outputConfGenerate(outputConfFp, areasX, areasY);

	// Close the files
	fclose(outputConfFp);
	fclose(areaConfFp);

	return 0;
}

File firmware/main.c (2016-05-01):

/*

   Copyright (C) 2013 Stephen Robinson
  
   This file is part of HDMI-Light
  
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
*/

#include <inttypes.h>
#include <avr/io.h>
#include <avr/pgmspace.h>
#include <avr/interrupt.h>
#include <string.h>
#include <stdio.h>
#include "ambilight.h"
#include "serial.h"
#include "i2c.h"


// If this line is commented out, the ADV7611 will not be started
// at power on and HDMI handshaking will not occur, in which case "R"
// needs to be run from the serial console to start the ADV7611
#define AUTO_INITIALIZATION

// Uncomment to enable power on/off via physical switch.
// Requires a pull-up resistor and switch to be added.
//#define ENABLE_POWER_SWITCH

#define BELL    '\a'


uint8_t silent = 0;
volatile uint8_t g_formatChanged = 0;
volatile uint8_t g_cecMessage[16];
volatile uint8_t g_cecMessageLength;


ISR(_VECTOR(1))
{
	g_formatChanged = 1;
	INT_CLEAR = 1;
}

ISR(_VECTOR(2))
{
	uint8_t cecRxIntState = i2cRead(0x98, 0x93);

	// if this is a CEC RX message 0 ready interupt
	if(cecRxIntState & 8)
	{
		int i;

		// copy the received message
		g_cecMessageLength = i2cRead(0x80, 0x25);
		if(g_cecMessageLength > sizeof(g_cecMessage))
			g_cecMessageLength = sizeof(g_cecMessage);
		for(i = 0; i < g_cecMessageLength; ++i)
			g_cecMessage[i] = i2cRead(0x80, 0x15 + i);

		// clear the message buffer ready for a new message
		i2cWrite(0x80, 0x2C, 0x02);

		// clear the interrupt
		i2cWrite(0x98, 0x94, 0x08);
	}
}

void idle()
{
#ifdef ENABLE_POWER_SWITCH
	static uint8_t debounceValue = 0;
	static uint8_t debounceTicks = 0;
#endif // ENABLE_POWER_SWITCH

	if(g_formatChanged)
	{
		changeFormat();
		g_formatChanged = 0;
	}

	if(g_cecMessageLength != 0)
	{
		cli();
		processCecMessage();
		g_cecMessageLength = 0;
		sei();
	}

#ifdef ENABLE_POWER_SWITCH
	if((PIND & (1 << GPIO_POWER_PIN)) == debounceValue)
	{
		if(debounceTicks == DEBOUNCE_TICK_COUNT)
		{
			if(debounceValue)
				powerOn();
			else
				powerOff();
			++debounceTicks;
		}
		else if(debounceTicks < DEBOUNCE_TICK_COUNT)
			++debounceTicks;
	}
	else
	{
		debounceValue = PIND & (1 << GPIO_POWER_PIN);
		debounceTicks = 0;
	}
#endif // ENABLE_POWER_SWITCH
}

// Print a section of the ring buffer to stdout, wrapping around when passing the end.
// Also replacing NULLs with spaces as old commands have had spaces replaced with NULLs
// when they were being split into args
void ringBufPrint(char* buf, uint8_t pos, int len)
{
	while(len--)
	{
		if(buf[pos] == '\0')
			fputc(' ', stdout);
		else
			fputc(buf[pos], stdout);
		++pos;
	}
}

void ringBufCopy(char* buf, uint8_t dst, uint8_t src, int len)
{
	while(len--)
		buf[dst++] = buf[src++];
}

void ringBufCopyReverse(char* buf, uint8_t dst, uint8_t src, int len)
{
	dst += len;
	src += len;
	while(len--)
		buf[--dst] = buf[--src];
}

char readcmd(char** argv, char maxargs)
{
	static char cmdbuf[256] = {0, 0};
	static unsigned char current = 0;

	unsigned char history = 0;
	unsigned char pos = current + 1;
	unsigned char end = current + 1;
	unsigned char arg;


	while(1)
	{
		int c = serial_getchar();
		if(c == -1)
		{
			idle();
			continue;
		}

		switch(c)
		{
			case 0x1B:
				while((c = serial_getchar()) == -1)
					;
				if(c == '[')
				{
					while((c = serial_getchar()) == -1)
						;
					switch(c)
					{
						case 'A': goto UP;
						case 'B': goto DOWN;
						case 'C': goto RIGHT;
						case 'D': goto LEFT;
					}
				}
				break;
			LEFT:
			case 0x02: // left
				if(pos - 1 != current)
				{
					--pos;
					printf_P(PSTR("\x1B[D")); // move left
				}
				else
					serial_putchar(BELL);
				break;
			case 0x08: // backspace
			case 0x7f:
				if(pos > 0)
				{
					// move partial line left in buffer to fill hole
					ringBufCopy(cmdbuf, pos - 1, pos, end - pos);
					--pos; --end;

					// move cursor left one place and print the partial line
					printf_P(PSTR("\x1B[D"));
					ringBufPrint(cmdbuf, pos, end - pos);

					// move the cursor left, back to the edit position
					printf_P(PSTR(" \x1B[%dD"), end - pos + 1);
				}
				else
					serial_putchar(BELL);
				break;
			RIGHT:
			case 0x06: // right
				if(pos + 1 != end)
				{
					++pos;
					printf_P(PSTR("\x1B[C")); // move right
				}
				else
					serial_putchar(BELL);
				break;
			case '\n':
			case '\r':
				goto DONE;
			UP:
			case 0x10:
				if(1)
				{
					unsigned char p = current;
					unsigned char len = 0;
					unsigned char i;

					for(i = 0; i < history + 1; ++i)
					{
						len = cmdbuf[p];
						if(len == 0)
							break;
						p -= len;
					}
					if(i == history + 1)
					{
						++history;

						// lines in the history are NULL terminated, remove the termination
						--len;

						// copy the old line into the current position in the buffer
						ringBufCopy(cmdbuf, current + 1, p + 1, len - 1);
						cmdbuf[current + len] = '\0';

						// move the cursor to the beginning of the line and print the copied line
						printf_P(PSTR(" \x1B[%dD"), pos - current);
						ringBufPrint(cmdbuf, current + 1, len - 1);

						// if the copied line is shorter then overwrite any extra characters with spaces
						if(end - (current + len) > 0)
						{
							for(i = 0; i < end - (current + len); ++i)
								serial_putchar(' ');
							printf_P(PSTR("\x1B[%dD"), end - (current + len));
						}
						end = current + len;
						pos = end;
					}
					else
						serial_putchar(BELL);
				}
				break;
			DOWN:
			case 0x0E:
				if(history > 1)
				{
					unsigned char p = current;
					unsigned char len;
					unsigned char i;

					--history;
					for(i = 0; i < history; ++i)
					{
						len = cmdbuf[p];
						if(len == 0)
							break;
						p -= len;
					}

					// the lines in the history are NULL terminated, remove the termination
					--len;

					// copy the old line to the current position in the buffer
					ringBufCopy(cmdbuf, current + 1, p + 1, len - 1);
					cmdbuf[current + len] = '\0';

					// move the cursor to the beginning of the line and print the copied line
					printf_P(PSTR(" \x1B[%dD"), pos - current);
					ringBufPrint(cmdbuf, current + 1, len - 1);

					// if the copied line is shorter then overwrite the extra characters with spaces
					if(end - (current + len) > 0)
					{
						for(i = 0; i < end - (current + len); ++i)
							serial_putchar(' ');
						printf_P(PSTR("\x1B[%dD"), end - (current + len));
					}
					end = current + len;
					pos = end;
				}
				else if(history == 1)
				{
				}
				else
					serial_putchar(BELL);
				break;
			default:
				if(end + 1 != current)
				{
					// copy any characters after the current edit point to the right to make room
					ringBufCopyReverse(cmdbuf, pos + 1, pos, end - pos);

					// add the new character
					cmdbuf[pos] = c;

					// print the buffer from the current edit point to the end
					ringBufPrint(cmdbuf, pos, end - pos + 1);

					// move the cursor back to the edit point
					printf_P(PSTR(" \x1B[%dD"), end - pos + 1);
					++pos;
					++end;

				}
				else
					serial_putchar(BELL);
				break;
		}
	}
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

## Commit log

2016-02-06 Port board to Papilio Duo
    Created a port of the HDMI-Light board to match the headers on a
    Papilio Duo instead of a Papilio Pro. They both have the same FPGA, so
    there should be no software changes required except changing the pin
    assignment of the FPGA.
    I added a footprint for an (optional) ZigBee module, since my plan is
    to integrate HDMI-Light as a moodlight when there is no HDMI signal,
    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
    [hdmilight-Duo.brd, hdmilight-Duo.sch]
2016-02-06 Ignore Eagle lock files
    Eagle CAD 7.something now generates lock files, but they shouldn't show
    up in a git status.
2016-05-01 Changes implementing external color override through SPI
    [hdmilight-Duo.brd, hdmilight-Duo.sch, hdmilight.brd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]

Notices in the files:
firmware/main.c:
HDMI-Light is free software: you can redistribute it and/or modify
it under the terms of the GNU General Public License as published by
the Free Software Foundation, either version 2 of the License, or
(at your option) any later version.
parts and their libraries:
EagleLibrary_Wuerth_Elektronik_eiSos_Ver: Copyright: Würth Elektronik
